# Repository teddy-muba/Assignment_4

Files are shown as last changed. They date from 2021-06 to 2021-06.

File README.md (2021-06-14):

# uHat PCB design - Status LEDs submodule

In a large library building configuration where cubicles are used as small isolated study or reading spaces, it is a common thing to see readers, immediately after walking in, seeking for an available cubicle to occupy.
Similarly, in a vast office building scenario where the majority of the company operates on the floor, it is common practice for both workers and managers to book rooms for meetings during working hours. On the other hand, it is sometimes a ritual for individual employees to leave their floor desks to make use of meeting rooms to focus in solitude. Most times, this second case doesn’t require any formal booking of the meeting room.
Another instance or scenario we can think of is an indicating system at a banking facility or any other higher security building where only one person is admissible at a time.
 
Looking at the practicality of how things should operate in the above three scenarios, we should always expect situations where it won’t be time-effective for a new person entering the library to simply walk up towards the cubicles section to see if there is any unavailable place and return to the waiting area section if that is the case, only to make the same trip moments later to see if there is any available cubical - repeating the back-and-forth until so. The same thing can be thought of disturbances that can happen in meeting rooms scenarios where one can open the room to check its availability while there is a meeting happening in there at the same time.  
Lastly, what about the nightmare people will be experiencing at the entrance of a building requiring only one person to enter the facility at a time in case there is no proper indication system. 
 
We can solve these situations by using lights. Our idea is to make use of a Pi HAT designed with a bunch of LEDs to serve as occupancy indicators with the idea of using universal signs for green and red, where green means available and red means occupied. In this specific project, we will design and simulate a piHAT that will use 10 LEDs connected to the GPIO pins to simulate the occupancy indications for 10 cubicles, 10 meeting rooms or 10 entrances of banking facilities.

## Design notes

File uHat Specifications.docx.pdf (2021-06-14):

## uHat Specifications

Considering the user acceptance criterias in the final report and looking at the operational approach for each requirement, here is how we will go about designing a HAT that is compatible with the Raspberry Pi sense HAT standards.

General Details

Our HAT board will be conform to the following add-on board requirements:

- It should have a valid ID EEPROM (including vendor info, GPIO map and valid device tree information).
- It should have a full size 40W GPIO connector.
- It should follow the HAT mechanical specification (https://github.com/raspberrypi/hats/blob/master/hat-board-mechanical.pdf) (See details in the below table 1.1).
- It should use a GPIO connector that spaces the HAT between 10mm and 12mm from the Pi (i.e. uses spacers between 10mm and 12mm).
- It should be able to supply 2.0A of current continuously to the Pi. We should consider back powering the Pi via a GPIO connector so the HAT should be able to supply a minimum of 1.3A continuously to the Pi.

Other details to consider:

- We should consider having some specific GPIO sequencing that should consist of having some pins being active by default, so they can have unexpected results in case there are no current limitations on LEDS connected to them.
- Nothing will be connected to pins 27 and 28 other than a valid EEPROM.
- We should consider back powering the Pi via the HAT, therefore it will be questionable to establish a clear need to connect the 3.3V supply from the HAT to the Pi.
- We should also consider putting in protective components to prevent 5V via USB causing conflicting power issues.

Design Specifications

- Pins configurations

We will put this part of the design into a spreadsheet to make it easier to parse all the options and to do some checking to see what is available and if the function assigned to a particular pin is valid. I have inserted both a screenshot and the link (read-only) to the in-progress work on the spreadsheet here:

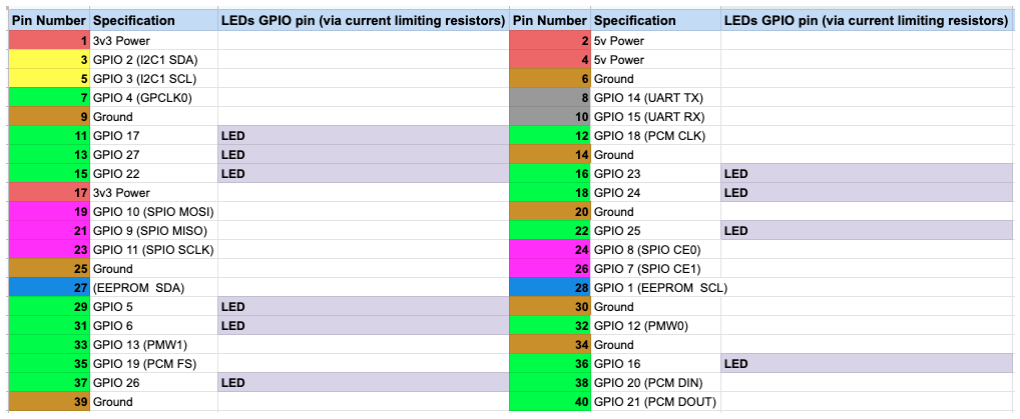
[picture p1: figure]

Figure 1: Pins configurations showing where our 10 LEDs will be connected.

https://docs.google.com/spreadsheets/d/16PtPY0GQPKd3i4CP3gYp-tbYzPIeMka0UuIFL_dlIac/edit#gid=0 (https://docs.google.com/spreadsheets/d/16PtPY0GQPKd3i4CP3gYp-tbYzPIeMka0UuIFL_dlIac/edit#gid=0)

Each pin will be numbered from 1 to 40, starting from the lower-left corner. These are the physical pin numbers.

Power and Ground

Highlighted in red will be power pins labeled 3 or 5 for 3.3V or 5V. These pins will allow us to send power to the device without the need for any code. There will not be a way to turn these off either.

There will be two power rails: 3.3 volts and 5 volts. The 3.3V rail will be limited to
50mA current draw. (https://elinux.org/RPi_Low-level_peripherals) In contrast, the 5V rail will provide whatever current capacity is left over from the power supply after the Pi has taken what it needs.

Highlighted in brown will be the ground pins (GND).

Note: 5V GPIO pins will be physical numbers 2 and 4 and 3.3V GPIO pins will be physical numbers 1 and 17. Ground GPIO pins will be physical numbers 6, 9, 14, 20, 25, 30, 34, and 39.

Input/Output Pins

The green pins will be generic input/output pins. These will be easily used as inputs or outputs without clashing with other functions such as I2C, SPI, or UART.

These pins will be sending power to LEDs and/or other components, or they can be used as an input to read sensors, switches, or other input devices.

The output power of these pins is 3.3V. Each pin shouldn't exceed 16mA of current, either sinking or sourcing. The entire set of GPIO pins shouldn't exceed more than 50mA at any one time. This can be restrictive, so I may have to get creative during the course of the project.

Note: Generic GPIO pins are physical numbers 7, 11, 12, 13, 15, 16, 18, 22, 29, 31, 32, 33, 35, 36, 37, 38, and 40.
In the figure, we have also shown to which pins our LEDs will be connected via current limitations resistors.

I2C Pins

The I2C pins will be in yellow. I2C (https://learn.sparkfun.com/tutorials/i2c) is a communication protocol that will allow devices to communicate with the Pi HAT. These pins can also be used as generic GPIO pins.

UART (Serial) Pins

The UART pins are shown in grey. These pins will be another communication protocol that offers serial connections and can be used as generic GPIO inputs/outputs.

One use for UART will be to enable a serial connection from a Pi to a laptop over USB. This should be achieved using add-on boards or simple cables. It will remove the need for a screen or internet connection to access our Pi.

Note: UART GPIO pins are physical pin numbers 8 and 10.

SPI Pins

The SPI pins will be in pink. SPI should be described as an interface bus that sends data between the Pi and other hardware and peripherals. It can commonly be used for chaining devices such as an LED (https://www.lifewire.com/light-an-led-with-the-raspberry-pis-gpio-4090226) matrix or display.

Note: SPI GPIO pins are physical pin numbers 19, 21, 23, 24, and 26.

DNC Pins

Last are two pins in blue that are currently labeled as DNC, which stands for Do Not Connect. As mentioned in our general details section, nothing will be connected to these pins other than a possible valid EEPROM.

Note: DNC GPIO pins are physical pin numbers 27 and 28.

## Mechanical Specifications

Requirement | Specification(s) | Acceptance Test Criteria
Minimum Hat Requirements | ● Pi HAT Board must be 65x56mm or 65x56.5mm ● Pi HAT Board must have a 3mm Radius corner ● Pi HAT Board much have 4 mounting holes in corners ● Pi HAT Board much follow mounting holes specifications ● Pi HAT Board have full 40W GPIO Connectors | ● Given the general dimensioning requirements of the Pi HAT ● When being manufactured ● Then ensure the Pi HAT Board dimensioning meet the listed specifications
Mounting Holes Specification | ● Mounting Holes should ideally be ● non-plated. If plated, hole and land must be electrically isolated (Not to be connected to ground). ● Mounting hole land should be min 6.2mm and either isolated copper or bare board (open solder mask) ● Mounting holes should be drilled to 2.75mm +/- 0.05mm | ● Given the holes requirements of the Pi HAT ● When being manufactured ● Then ensure the Pi HAT Board holes requirements meet the listed specifications

Table.1.1: Mechanical specifications

## Electrical Specification

Requirement | Specification(s) | Acceptance Test Criteria
Power Source | Pin Name: +5V, +3.3V, GND and Vin Description: ● +5V -power output ● +3.3V -power output ● GND – GROUND pin | ● Given the power source ● When our designed Pi Hat has to be powered ● Then we should ensure output, input and ground meet the specification
Processor Operating Voltage | 3.3V | ● Given the Processor Operating Voltage ● When powered ● Then we should ensure Processor Operating Voltage meets the specification
Raw Voltage input | 5V, 2A power source | ● We should ensure Raw Voltage input meets the specification
Maximum current through each I/O pin | 16mA | ● We should ensure Maximum current through each I/O pin meets the specification
Maximum total current drawn from all I/O pins | 54mA | ● We should ensure Maximum total current drawn from all I/O pins meets the specification

Table1.2: Electrical specifications

Functional Specifications

Requirement | Specification(s) | Acceptance Test Criteria
System Processing Size | ● With 1.2 GHZ clock speed and 1GB RAM | ● Given the system processing size ● When the Pi HAT is designed ● Then, its system processing size should meet the required specifications to perform our described use case
Wireless Functionality | ● Wireless LAN and Bluetooth facility | ● Given the wireless functionality ● When wireless connectivity is needed ● Then our designed Pi HAT should be implemented with wireless LAN and bluetooth facility by which WIFI HOTSPOT for internet connectivity can be setup
LCD display | ● LCD display port | ● Specification should be met by allowing the Pi HAT to have a dedicated port for connecting LCD display
Camera | ● Camera port | ● Specification should be met by allowing the Pi HAT to have a

dedicated camera port so one can connect the camera without any hassle to the PI board.
PMW | ● PMW Outputs | ● Specification should be met by allowing the Pi HAT to have PMW outputs for application use.

Table 1.3: Functional specifications

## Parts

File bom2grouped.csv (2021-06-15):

Reference | Quantity | Value | Footprint | Price in ZAR | Total Price in ZAR | Part Page | Datasheet
D1 D2 D3 D4 D5 D6 D7 D8 D9 D10 | 10 | CQY99 | LED_THT:LED_D5.0mm_Horizontal_O1.27mm_Z3.0mm_IRGrey | 19.79 | 197.90 | https://www.conrad.com/p/vishay-tsus-5401-cqy99-ir-emitter-950-nm-22-5-mm-radial-lead-184500?insert=CJ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 | https://www.prtice.info/IMG/pdf/CQY99.pdf
Q1 | 1 | 2N2219 | digikey-footprints:TO-39-3 | 34.35 | 34.35 | https://www.digikey.co.za/product-detail/en/central-semiconductor-corp/2N2219-PBFREE/1514-2N2219PBFREE-ND/4806843 | http://www.onsemi.com/pub_link/Collateral/2N2219-D.PDF
Q2 | 1 | 2N3905 | digikey-footprints:TO-92-3 | 6.09 | 6.09 | https://www.digikey.co.za/product-detail/en/central-semiconductor-corp/2N3905-PBFREE/1514-2N3905PBFREE-ND/4806877 | https://www.nteinc.com/specs/original/2N3905_06.pdf
BT1 | 1 | 5V supply | Battery:Battery_Panasonic_CR1025-VSK_Vertical_CircularHoles | 14.29 | 14.29 | https://www.digikey.com/en/products/detail/panasonic-bsg/CR-1025-BN/269738 | ~
R1 R2 R3 R4 R5 R6 R7 R8 R9 R10 | 10 | 300 | Resistor_THT:R_Axial_DIN0207_L6.3mm_D2.5mm_P7.62mm_Horizontal | 3.05 | 30.50 | https://www.digikey.co.za/product-detail/en/vishay-beyschlag-draloric-bc-components/MBA02040C3000FRP00/BC3491CT-ND/7350921 | ~
R11 | 1 | 55 | Resistor_THT:R_Axial_DIN0207_L6.3mm_D2.5mm_P7.62mm_Horizontal | 0.86 | 0.86 | https://za.rs-online.com/web/p/through-hole-fixed-resistors/1743006/?matchtype=&pla-303060399558&gclsrc=aw.ds | ~
R12 | 1 | 10 | Resistor_THT:R_Axial_DIN0207_L6.3mm_D2.5mm_P7.62mm_Horizontal | 7.76 | 7.76 | https://www.digikey.co.za/product-detail/en/yageo/PNP300JR-73-10R/10AECT-ND/2059154 | ~
R13 | 1 | 1k | Resistor_THT:R_Axial_DIN0207_L6.3mm_D2.5mm_P7.62mm_Horizontal | 2.36 | 2.36 | https://za.rs-online.com/web/p/through-hole-fixed-resistors/7078669/?matchtype=&pla-450541326901&gclsrc=aw.ds | ~
R14 | 1 | 22k | Resistor_THT:R_Axial_DIN0207_L6.3mm_D2.5mm_P7.62mm_Horizontal | 1.61 | 1.61 | https://www.banggood.com/60pcs-2W-22KR-Metal-Film-Resistor-Resistance-1-pencent-22K-ohm-Resistor-p-1679184.html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 | ~
R15 | 1 | 10k | Resistor_THT:R_Axial_DIN0207_L6.3mm_D2.5mm_P7.62mm_Horizontal | 0.59 | 0.59 | https://www.amazon.in/Deepak-Enterprise-carbon-film-resistor/dp/B01MYSUG1Q | ~
U1 | 1 | LTC4414 | Package_SO:MSOP-8_3x3mm_P0.65mm | 73.95 | 73.95 | https://www.findchips.com/search/LTC4414 | http://cds.linear.com/docs/en/datasheet/4414fc.pdf
H1 H2 H3 H4 | 4 | MountingHole | lib:MountingHole_2.7mm_M2.5_uHAT_RPi |  | 0.00 |  | ~
J1 | 1 | GPIO_CONNECTOR | lib:PinSocket_2x20_P2.54mm_Vertical_Centered_Anchor |  | 0.00 |  | ~

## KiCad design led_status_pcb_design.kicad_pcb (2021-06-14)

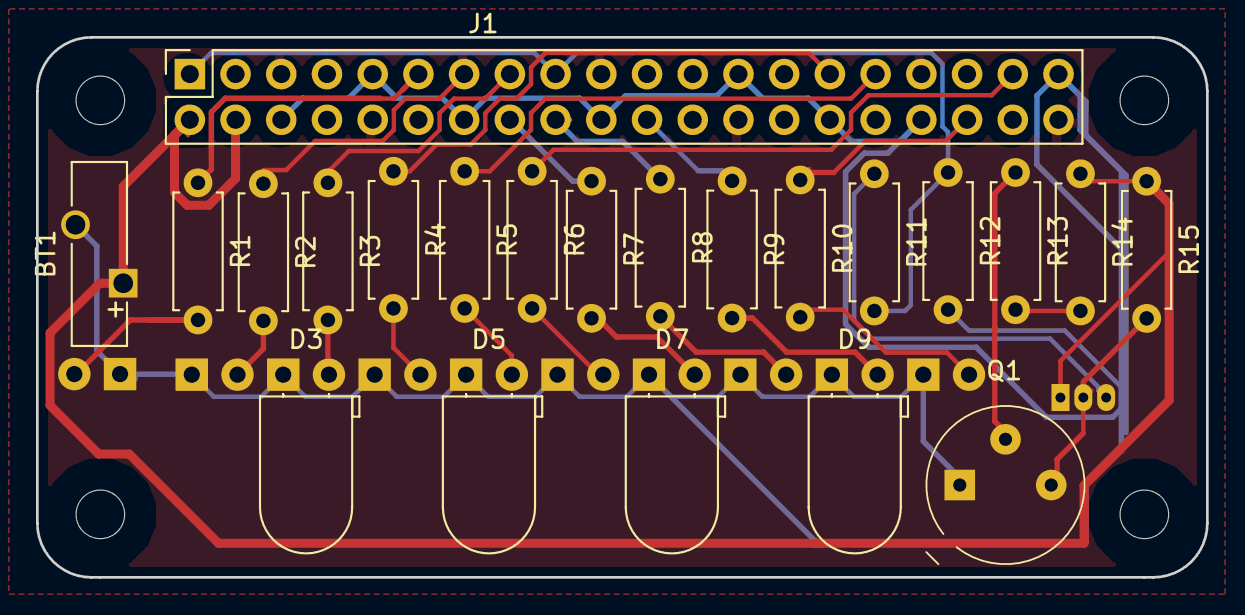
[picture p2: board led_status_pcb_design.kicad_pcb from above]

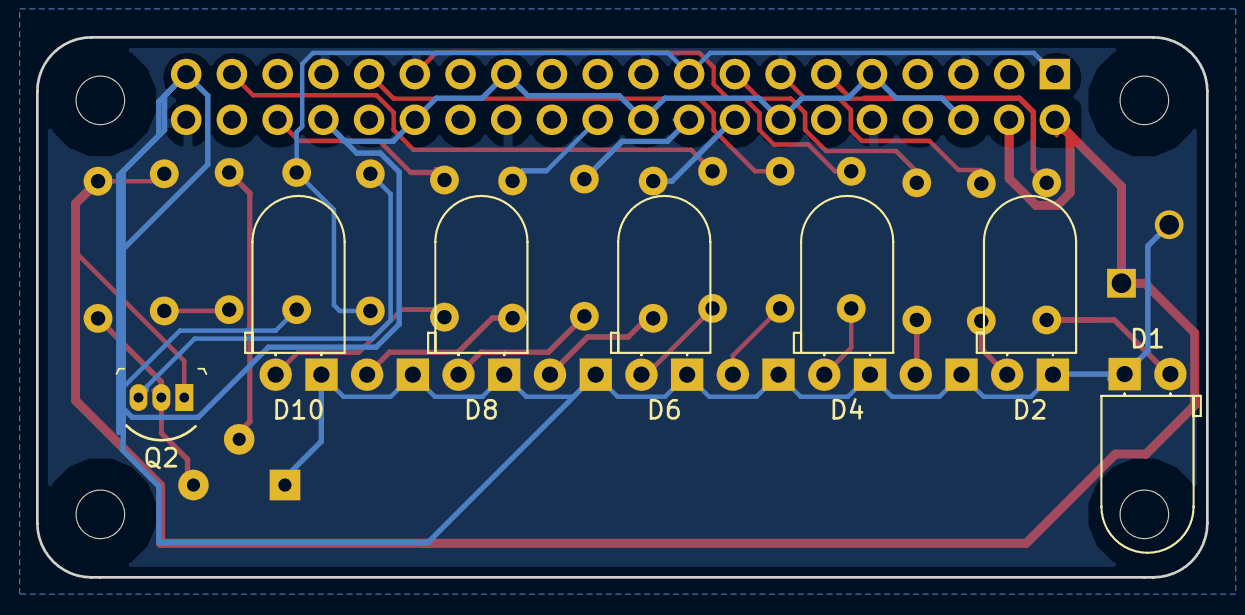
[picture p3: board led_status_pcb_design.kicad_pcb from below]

Board: 2 copper layers, 65.0 x 30.0 mm, 33 parts (7 on the bottom side), 27 nets.

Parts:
BT1: 5V supply; Battery_Panasonic_CR1025-VSK_Vertical_CircularHoles
D1, D2, D3, D4, D5, D6, D7, D8, D9, D10: CQY99; LED_D5.0mm_Horizontal_O1.27mm_Z3.0mm_IRGrey
H1, H2, H3, H4: MountingHole; MountingHole_2.7mm_M2.5_uHAT_RPi
J1: GPIO_CONNECTOR; PinSocket_2x20_P2.54mm_Vertical_Centered_Anchor
Q1: 2N2219; TO-39-3
Q2: 2N3905; TO-92-3
R1, R2, R3, R4, R5, R6, R7, R8, R9, R10: 300; R_Axial_DIN0207_L6.3mm_D2.5mm_P7.62mm_Horizontal
R11: 55; R_Axial_DIN0207_L6.3mm_D2.5mm_P7.62mm_Horizontal
R12: 10; R_Axial_DIN0207_L6.3mm_D2.5mm_P7.62mm_Horizontal
R13: 1k; R_Axial_DIN0207_L6.3mm_D2.5mm_P7.62mm_Horizontal
R14: 22k; R_Axial_DIN0207_L6.3mm_D2.5mm_P7.62mm_Horizontal
R15: 10k; R_Axial_DIN0207_L6.3mm_D2.5mm_P7.62mm_Horizontal

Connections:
+3V3: J1.1, J1.17, R11.2, R12.1
+5V: BT1.1, J1.2, J1.4, Q2.1, R14.1, R15.1
/GPIO5: J1.29, R4.1
/GPIO6: J1.31, R5.1
/GPIO16: J1.36, R10.1
/GPIO17_GEN0: J1.11, R1.1
/GPIO22_GEN3: J1.15, R3.1
/GPIO23_GEN4: J1.16, R7.1
/GPIO24_GEN5: J1.18, R8.1
/GPIO25_GEN6: J1.22, R9.1
/GPIO26: J1.37, R6.1
/GPIO27_GEN2: J1.13, R2.1
GND: BT1.2, D1.1, D2.1, D3.1, D4.1, D5.1, D6.1, D7.1, D8.1, D9.1, D10.1, J1.6, J1.9, J1.14, J1.20, J1.25, J1.30, J1.34, J1.39, Q1.1, R12.2
unnamed: D1.2, R1.2
unnamed: D2.2, R2.2
unnamed: D3.2, R3.2
unnamed: D4.2, R4.2
unnamed: D5.2, R5.2
unnamed: D6.2, R6.2
unnamed: D7.2, R7.2
unnamed: D8.2, R8.2
unnamed: D9.2, R9.2
unnamed: D10.2, R10.2
unnamed: Q1.2, R13.1
unnamed: Q1.3, Q2.2, R15.2
unnamed: Q2.3, R11.1
unnamed: R13.2, R14.2

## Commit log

2021-06-14 project schematics
    [led_status_pcb_design.sch]
2021-06-14 project pcb
    [led_status_pcb_design.kicad_pcb]
2021-06-14 gerbers files
    [led_status_pcb_design-B_Cu.gbl, led_status_pcb_design-B_Mask.gbs, led_status_pcb_design-B_SilkS.gbo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]
2021-06-14 simulated circuit

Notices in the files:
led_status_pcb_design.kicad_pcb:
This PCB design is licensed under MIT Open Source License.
